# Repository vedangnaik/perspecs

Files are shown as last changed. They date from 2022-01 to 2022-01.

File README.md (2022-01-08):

# Perspecs

Perspecs is a 3D-printed frame for my spectacles. The name is a play on 'perspex', a type of plastic, and 'specs', a commonly-used shorthand for spectacles. Smart spectacles like the A.I. powered ones worn by Iron Man and Spiderman have always captured my imagination; this project was a way for me to explore that idea in real life. 

In this model, the custom nosepeice and temples allow for all sorts of interesting things to be encased within; for example, in the picture below, I've created a SD card holder in the right temple. With slight modifications, one could also embed small PCBs, batteries, and other doodads to enable all sorts of functionality.



*Note: These models have been custom-made for my prescription lenses. Do not expect them to work out of the box for yours. However, the models should make a good starting point for customization.*

## Parts
1. 3D-printer-ready PLA plastic
2. Replacement spectacle nose pads

## Tools
1. Solidworks 2020
2. Cura
3. AnyCubic Chiron
4. Sandpaper and scissors
5. Hot glue gun

## Cura Settings
The settings below produced decent results on the Chiron I used. The base template was the default Cura `0.1` template, with the following changes made for each part. All parts were printed with only walls and 0% infill.
* `bridge.SLDPRT`:
  - Print speed: 15 mm/s
  - Build plate adhesion: Brim
  - Wall count: 12
* `left_temple.SLDPRT` and `right_temple.SLDPRT`:
  - Print speed: 25 mm/s
  - Build plate adhesion: Skirt, 4 layers
  - Wall count: 6

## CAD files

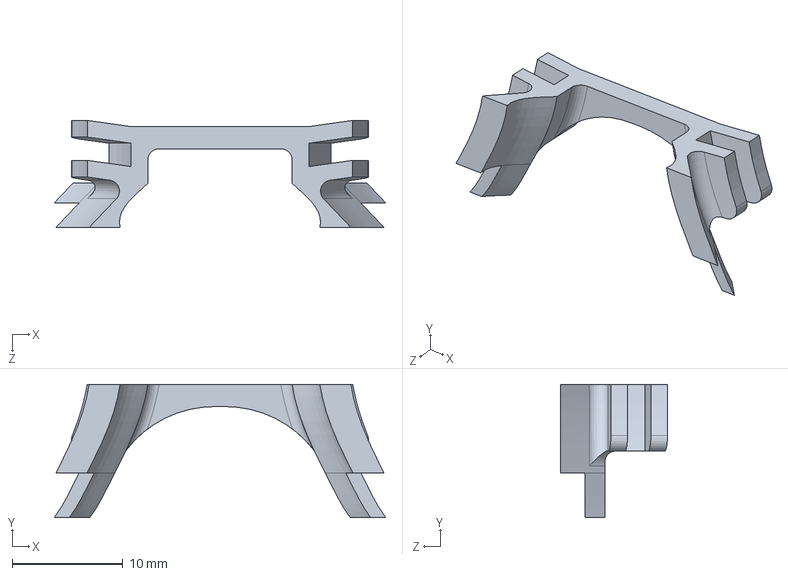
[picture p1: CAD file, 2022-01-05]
bridge.SLDPRT
29.9 x 12.0 x 9.66 mm

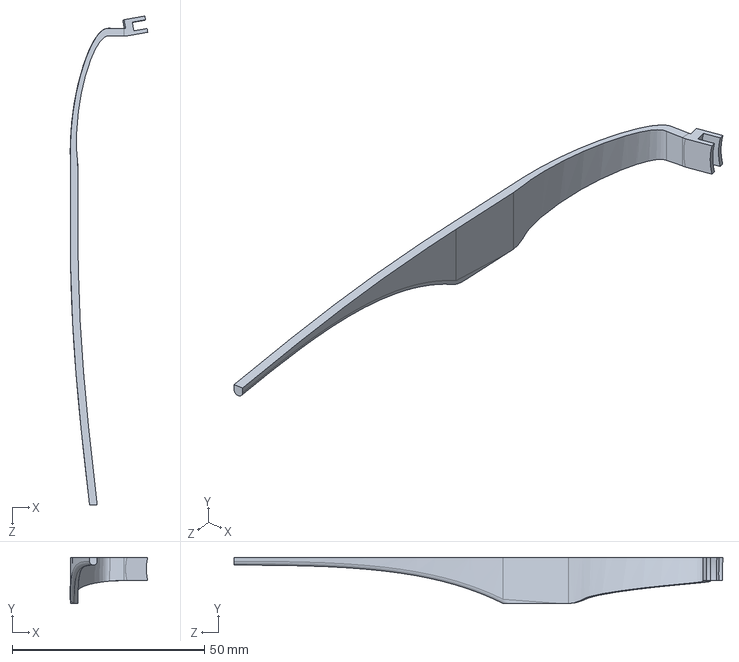
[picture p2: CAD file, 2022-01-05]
left_temple.SLDPRT
20.2 x 12.0 x 127.2 mm

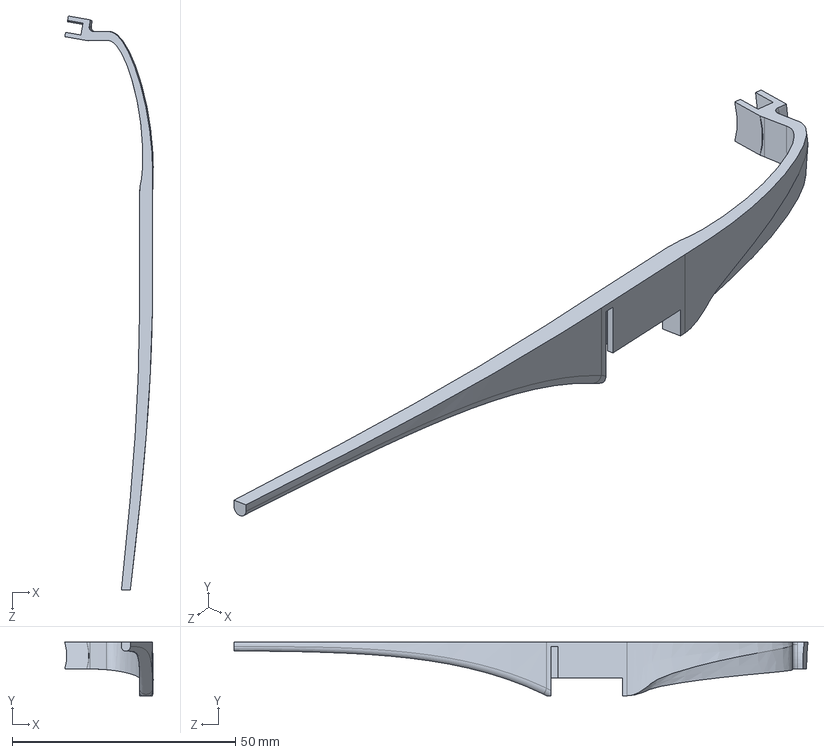
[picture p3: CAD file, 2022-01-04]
right_temple.SLDPRT
19.8 x 12.0 x 128.5 mm

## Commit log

2021-12-24 Changed arm holder
    [temples.SLDPRT]
2021-12-25 Working on v2
    [bridge.SLDPRT, left_temple.SLDPRT, right_temple.SLDPRT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]
2021-12-27 Finalized bridge design for now
    [bridge.SLDPRT]
2021-12-27 Working on integrating card holder with frame
    [right_temple.SLDPRT]
2021-12-27 v1 of integrated card holder
    [right_temple.SLDPRT]
2021-12-28 Checkpointing working integration
    [right_temple.SLDPRT]
2021-12-28 Printed and tested full right temple
    [right_temple.SLDPRT]
2021-12-28 Added card holder as separate model
    [card_holder.SLDPRT]
2021-12-29 Finalized on better card holder
    [card_holder.SLDPRT]
2021-12-29 Remodelled left temple with frame straight
    [left_temple.SLDPRT]
2021-12-29 New cardholder and integration into left temple
    [card_holder.SLDPRT, left_temple.SLDPRT]
2021-12-30 Started working on reversed holder in right temple
    [right_temple.SLDPRT]
2021-12-30 Checkpointing reduced-clamp right temple
    [right_temple.SLDPRT]
2021-12-30 Checkpointing left temple based on right
    [left_temple.SLDPRT]
2022-01-01 Started working on noseguard for bridge
    [bridge.SLDPRT]
2022-01-01 Finalized design for integrated card holder
    [right_temple.SLDPRT]
2022-01-04 Added more curved model for left and right temple based on wearing experience of straight models
    [left_temple.SLDPRT, right_temple.SLDPRT]
2022-01-05 Final changes for wearable v1
    [bridge.SLDPRT, left_temple.SLDPRT]
2022-01-05 Removed card holder model
    [card_holder.SLDPRT]
